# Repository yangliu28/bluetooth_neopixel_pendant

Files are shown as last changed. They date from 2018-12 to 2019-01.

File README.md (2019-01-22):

# bluetooth_neopixel_pendant

The circuit is designed on top of Arduino Micro, but changing the I/O level and clock to 3.3v and 8MHz respectively. The MCU has been loaded the same bootloader and fuses with [Sparkfun Pro Micro](https://www.sparkfun.com/products/12587). To upload program, [install Sparkfun Arduino Boards](https://github.com/sparkfun/Arduino_Boards#installation-instructions) to your Arduino IDE, and choose "Sparkfun Pro Micro" as board, and "Atmega32U4 (3.3v, 8 MHz)" as processor. The onboard bluetooth module HC-06 works only with Android and Windows, not iOS.

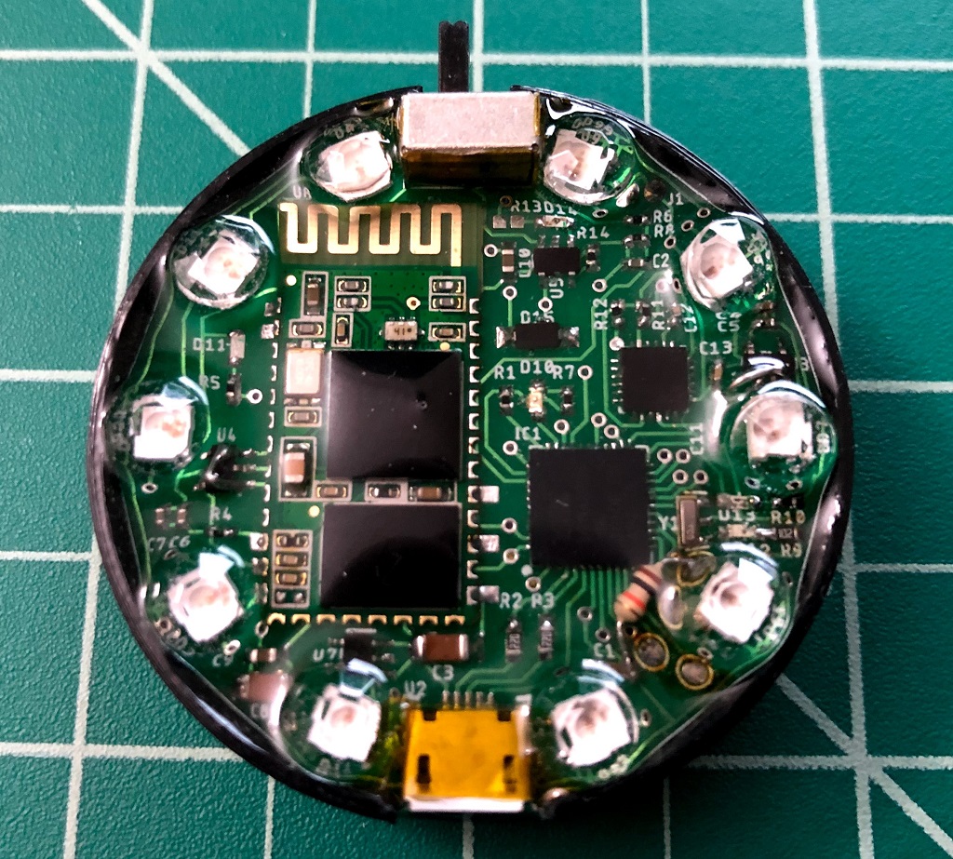
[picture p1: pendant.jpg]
pendant


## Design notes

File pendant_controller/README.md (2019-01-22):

## Hardware design

ATMEGA32U4 has built-in USB interface, for easily reprogramming the device without a USB to serial converter. The system is powered at 3.3v and clocked at 8MHz. Bluetooth module is HC-06 configured in slave mode. RGB LEDs are Neopixel Nano, with a small footprint of 2.4x2.7mm.

Diameter of the circular PCB is 1.7in, radius of 850 mil.

Matlab script to generate pos and orientation of neopixels:
```
d=735;
pos=zeros(10:3);
pos(1:5,1) = 850+d*cos((90+22+34*n)*pi/180);
pos(6:10,1) = 850+d*cos((-90+22+34*n)*pi/180);
pos(1:5,2) = 850+d*sin((90+22+34*n)*pi/180);
pos(6:10,2) = 850+d*sin((-90+22+34*n)*pi/180);
pos(1:5,3) = -180+22+34*n;
pos(6:10,3) = 22+34*n;
```

### Board fix

post-assembly modifications

**Reset pin of ATMEGA32U4 was be pulled up to 3V3 with a 10K resistor**

**Enable pins of two regulators for bluetooth and IMU were not working, because the voltage level of enable pin does not match output. Jumpers were used to keep regulators enabled always.**

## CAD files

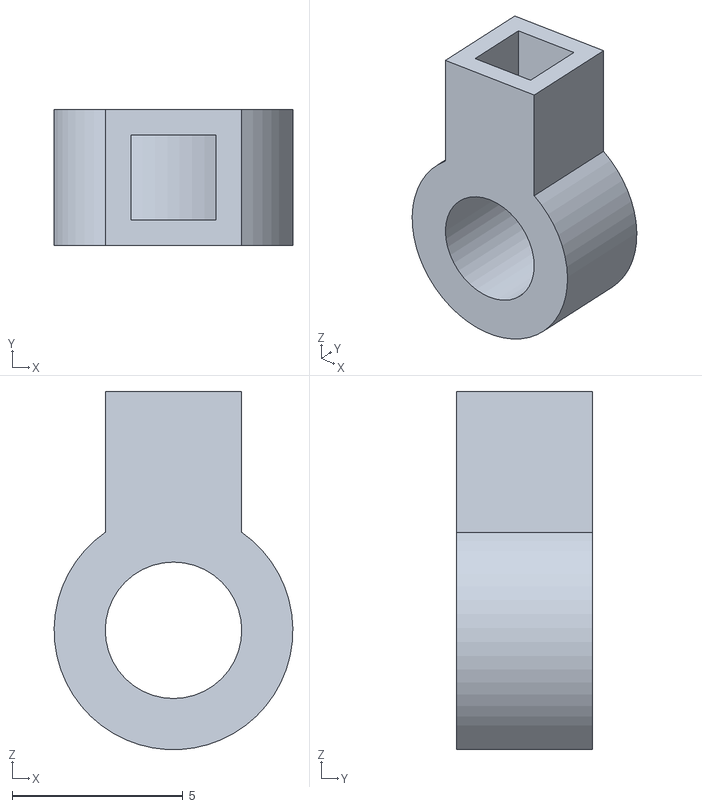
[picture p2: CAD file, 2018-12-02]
pendant case CAD/pendant_connector.STL
7.00 x 4.00 x 10.5

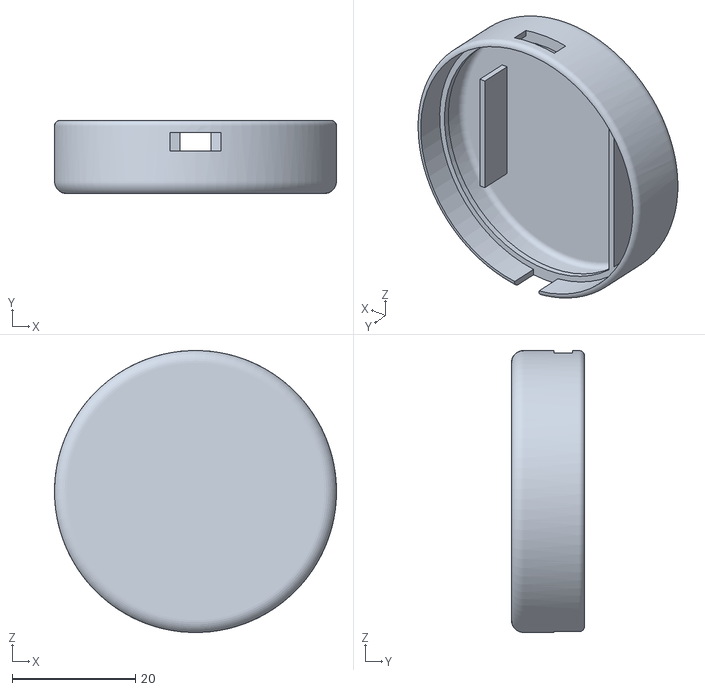
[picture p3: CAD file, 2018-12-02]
pendant case CAD/pendant_case.STL
45.7 x 11.9 x 45.8

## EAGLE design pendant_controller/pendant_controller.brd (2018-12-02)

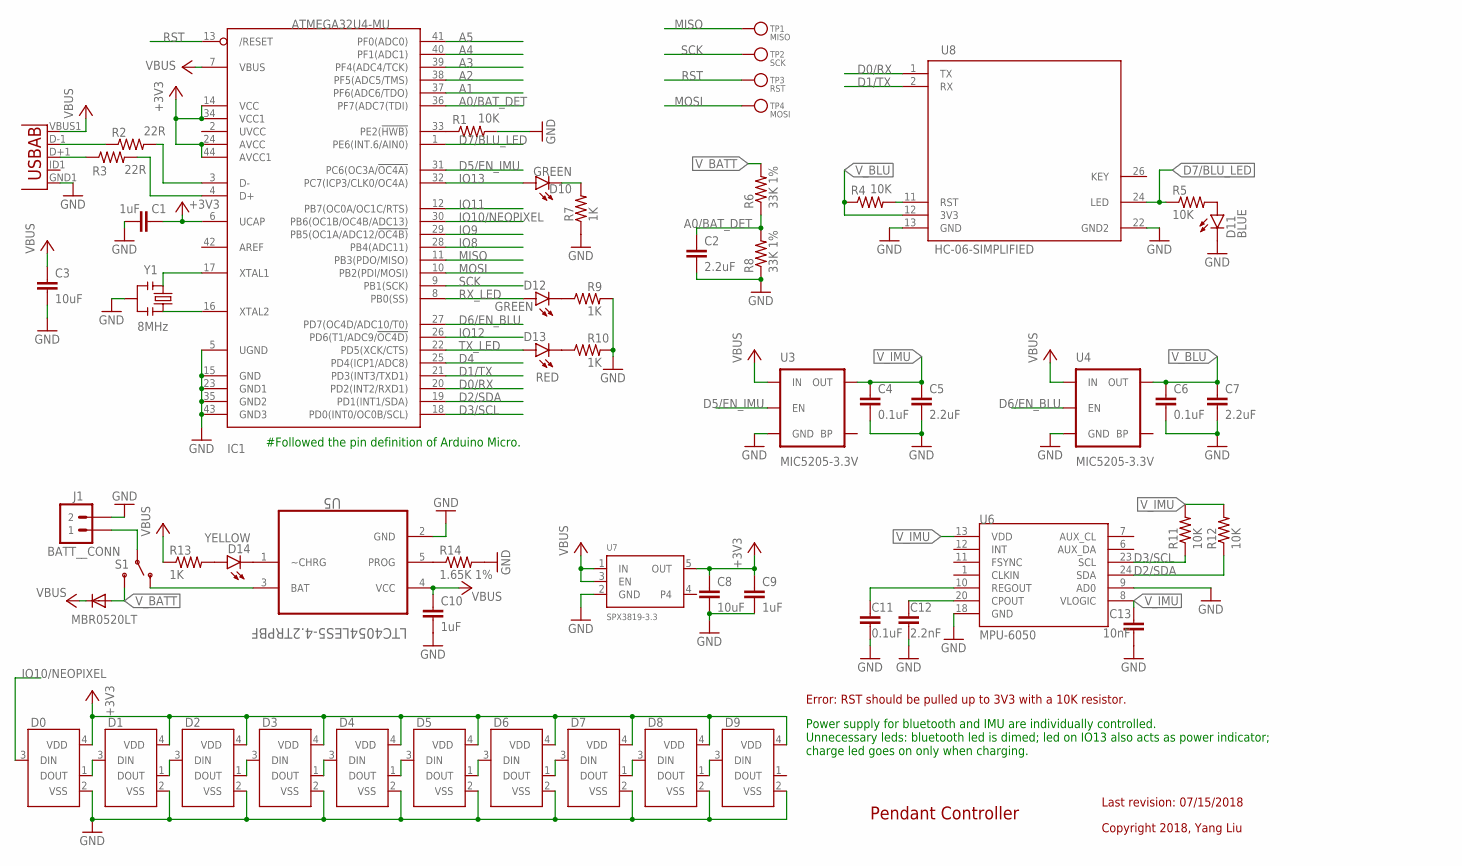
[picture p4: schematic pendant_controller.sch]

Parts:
C1, C9, C10: 1uF; 0603-CAP
C2, C5, C7: 2.2uF; 0402-CAP
C3, C8: 10uF; 1206
C4, C6, C11: 0.1uF; 0402-CAP
C12: 2.2nF; 0402-CAP
C13: 10nF; 0402-CAP
D0, D1, D2, D3, D4, D5, D6, D7, D8, D9: NEOPIXEL-2427; LED2427
D10, D12: GREEN; LED-0603
D11: BLUE; LED-0603
D13: RED; LED-0603
D14: YELLOW; LED-0603
D15: MBR0520LT; SOD123
IC1: ATMEGA32U4-MU; TQFN44_7MM
J1: BATT__CONN; 1X02-SMALL
R1, R4, R5, R11, R12: 10K; 0402-RES
R2, R3: 22R; 0603-RES
R6, R8: 33K 1%; 0402-RES
R7, R9, R10, R13: 1K; 0402-RES
R14: 1.65K 1%; 0402-RES
S1: SWITCH-SPDTPTH; SWITCH-SPDT
TP1: MISO; TESTPOINT_ROUND_1.5MM
TP2: SCK; TESTPOINT_ROUND_1.5MM
TP3: RST; TESTPOINT_ROUND_1.5MM
TP4: MOSI; TESTPOINT_ROUND_1.5MM
U2: USB""; USB-MICRO-SMD
U3, U4: MIC5205-3.3V; SOT23-5
U5: LTC4054LES5-4.2TRPBF; SOT95P280X100-5N
U6: MPU-6050; QFN-24
U7: SPX3819-3.3; SOT23-5
U8: HC-06-SIMPLIFIED; HC-06_SMD
Y1: 8MHz; RESONATOR-SMD

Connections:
+3V3: C1.1, C8.1, C9.1, D0.4 (VDD), D1.4 (VDD), D2.4 (VDD), D3.4 (VDD), D4.4 (VDD), D5.4 (VDD), D6.4 (VDD), D7.4 (VDD), D8.4 (VDD), D9.4 (VDD), IC1.6 (UCAP), IC1.14 (VCC), IC1.24 (AVCC), IC1.34 (VCC1), IC1.44 (AVCC1), U7.5 (OUT)
A0/BAT_DET: C2.1, IC1.36 (PF7(ADC7(TDI)), R6.1, R8.2
A1: IC1.37 (PF6(ADC6/TDO))
A2: IC1.38 (PF5(ADC5/TMS))
A3: IC1.39 (PF4(ADC4/TCK))
A4: IC1.40 (PF1(ADC1))
A5: IC1.41 (PF0(ADC0))
D0/RX: IC1.20 (PD2(INT2/RXD1)), U8.1 (TX)
D1/TX: IC1.21 (PD3(INT3/TXD1)), U8.2 (RX)
D2/SDA: IC1.19 (PD1(INT1/SDA)), R12.1, U6.24 (SDA)
D3/SCL: IC1.18 (PD0(INT0/OC0B/SCL)), R11.1, U6.23 (SCL)
D4: IC1.25 (PD4(ICP1/ADC8))
D5/EN_IMU: IC1.31 (PC6(OC3A/!OC4A)), U3.3 (EN)
D6/EN_BLU: IC1.27 (PD7(OC4D/ADC10/T0)), U4.3 (EN)
D7/BLU_LED: IC1.1 (PE6(INT.6/AIN0)), R5.1, U8.24 (LED)
GND: C1.2, C2.2, C3.2, C4.2, C5.2, C6.2, C7.2, C8.2, C9.2, C10.2, C11.2, C12.2, C13.2, D0.2 (VSS), D1.2 (VSS), D2.2 (VSS), D3.2 (VSS), D4.2 (VSS), D5.2 (VSS), D6.2 (VSS), D7.2 (VSS), D8.2 (VSS), D9.2 (VSS), D11.C, IC1.5 (UGND), IC1.15 (GND), IC1.23 (GND1), IC1.35 (GND2), IC1.43 (GND3), J1.2, R1.2, R7.1, R8.1, R9.2, R10.2, R14.2, U2.GND1 (GND), U3.2 (GND), U4.2 (GND), U5.2 (GND), U6.9 (AD0), U6.18 (GND), U7.2 (GND), U8.13 (GND), U8.22 (GND2), Y1.2
IO8: IC1.28 (PB4(ADC11))
IO9: IC1.29 (PB5(OC1A/ADC12/!OC4B))
IO10/NEOPIXEL: D0.3 (DIN), IC1.30 (PB6(OC1B/OC4B/ADC13))
IO11: IC1.12 (PB7(OC0A/OC1C/RTS))
IO12: IC1.26 (PD6(T1/ADC9/!OC4D))
IO13: D10.A, IC1.32 (PC7(ICP3/CLK0/OC4A))
MISO: IC1.11 (PB3(PDO/MISO)), TP1.P$1
MOSI: IC1.10 (PB2(PDI/MOSI)), TP4.P$1
unnamed: S1.1 (O), U5.3 (BAT)
unnamed: J1.1, S1.2
unnamed: R2.1, U2.D-1 (D-)
unnamed: D14.A, R13.2
unnamed: R3.1, U2.D+1 (D+)
unnamed: IC1.33 (PE2(!HWB)), R1.1
unnamed: IC1.4 (D+), R3.2
unnamed: R14.1, U5.5 (PROG)
unnamed: D14.C, U5.1 (~CHRG)
unnamed: D0.1 (DOUT), D1.3 (DIN)
unnamed: IC1.16 (XTAL2), Y1.3
unnamed: IC1.17 (XTAL1), Y1.1
unnamed: IC1.3 (D-), R2.2
unnamed: D12.C, R9.1
unnamed: D13.C, R10.1
unnamed: C12.1, U6.20 (CPOUT)
unnamed: C11.1, U6.10 (REGOUT)
unnamed: R4.2, U8.11 (RST)
unnamed: D10.C, R7.2
unnamed: D11.A, R5.2
unnamed: D1.1 (DOUT), D2.3 (DIN)
unnamed: D2.1 (DOUT), D3.3 (DIN)
unnamed: D3.1 (DOUT), D4.3 (DIN)
unnamed: D4.1 (DOUT), D5.3 (DIN)
unnamed: D5.1 (DOUT), D6.3 (DIN)
unnamed: D6.1 (DOUT), D7.3 (DIN)
unnamed: D7.1 (DOUT), D8.3 (DIN)
unnamed: D8.1 (DOUT), D9.3 (DIN)
RST: IC1.13 (/RESET), TP3.P$1
RX_LED: D12.A, IC1.8 (PB0(SS))
SCK: IC1.9 (PB1(SCK)), TP2.P$1
TX_LED: D13.A, IC1.22 (PD5(XCK/CTS))
VBUS: C3.1, C10.1, D15.C, IC1.7 (VBUS), R13.1, U2.VBUS1 (VBUS), U3.1 (IN), U4.1 (IN), U5.4 (VCC), U7.1 (IN), U7.3 (EN)
V_BATT: D15.A, R6.2, S1.3 (S)
V_BLU: C6.1, C7.1, R4.1, U4.5 (OUT), U8.12 (3V3)
V_IMU: C4.1, C5.1, C13.1, R11.2, R12.2, U3.5 (OUT), U6.8 (VLOGIC), U6.13 (VDD)

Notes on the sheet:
Last revision: 07/15/2018
Copyright 2018, Yang Liu
Pendant Controller
#Followed the pin definition of Arduino Micro.
Power supply for bluetooth and IMU are individually controlled. Unnecessary leds: bluetooth led is dimed; led on IO13 also acts as power indicator; charge led goes on only when charging.
Error: RST should be pulled up to 3V3 with a 10K resistor.

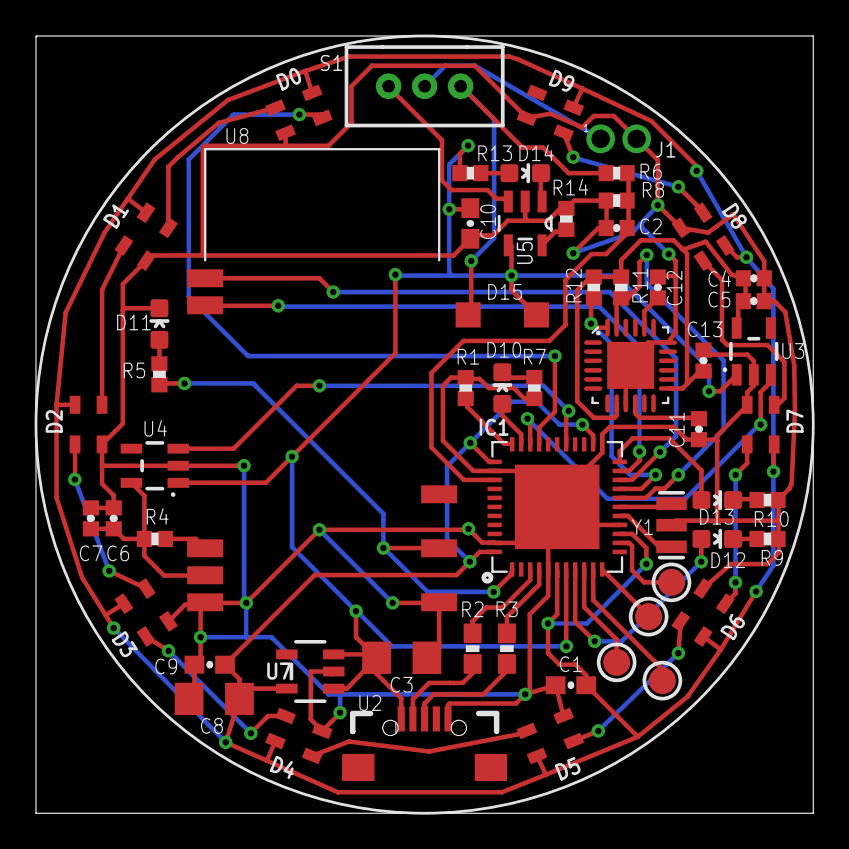
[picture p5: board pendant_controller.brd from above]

Board: 2 copper layers, 43.2 x 43.2 mm, 58 parts (0 on the bottom side), 50 nets.

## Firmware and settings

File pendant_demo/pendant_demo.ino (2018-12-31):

// This is the demo program for this bluetooth-neopixel pendant.
// Author: Yang Liu, 12/04/2018.

// Received string should end with carriage return(13), then line feed(10)
// Bluetooth command format: keyword + space + argument(optional)
// Singular commands
    // "rainbow", rainbow mode
// Combinational commands:
    // "brightness ##", 1 min brightness, 0 max brightness, 255 just below max
    // "all color_name", set all neopixels to same color
    // "led# color_name", addressing neopixels individuallly, number from 0 to 9
    // "gravity color_name", gravity mode
// Supported color names:
// white, black, maroon, brown, olive, teal, navy, red, orange, yellow, lime
// green, cyan, blue, pruple, magenta, grey, pink, apricot, beige, mint, lavender

// The circuit board shares the same body frame with the IMU.
// If facing the PCB, x axis points to the right,
// y axis points up to the switch, z axis points out from the board.

// List of distinct colors:
// https://sashat.me/2017/01/11/list-of-20-simple-distinct-colors/

#include <Adafruit_NeoPixel.h>
#include "Wire.h"
#include "I2Cdev.h"
#include "MPU6050.h"
#include "math.h"

#define NEOPIXEL_PIN 10
#define NEOPIXEL_NUM 10
#define MPU6050_ADDRESS 0x68
#define BUFFER_LEN 20
#define BATTERY_MEASURE A0
#define LED13 13

// MPU6050 variables
MPU6050 mpu6050;
int16_t accelCount[3];  // Stores the 16-bit signed accelerometer sensor output
float ax, ay, az;       // Stores the real accel value in g's
int16_t gyroCount[3];   // Stores the 16-bit signed gyro sensor output
float gx, gy, gz;       // Stores the real gyro value in degrees per seconds
float aRes = 2.0/32768.0;
float gRes = 250.0/32768.0;
float q[4] = {1.0f, 0.0f, 0.0f, 0.0f};  // vector to hold quaternion
float roll, pitch, yaw;  // in degrees
// for quaternion update
float GyroMeasError = PI * (40.0f / 180.0f);     // gyroscope measurement error in rads/s (start at 60 deg/s), then reduce after ~10 s to 3
float beta = sqrt(3.0f / 4.0f) * GyroMeasError;  // compute beta
float GyroMeasDrift = PI * (2.0f / 180.0f);      // gyroscope measurement drift in rad/s/s (start at 0.0 deg/s/s)
float zeta = sqrt(3.0f / 4.0f) * GyroMeasDrift;  // compute zeta, the other free parameter in the Madgwick scheme usually set to a small or zero value
float deltat = 0.0f;
float p_vect[3];

// Neopixel variables
Adafruit_NeoPixel pixels = Adafruit_NeoPixel(NEOPIXEL_NUM, NEOPIXEL_PIN, NEO_GRB + NEO_KHZ800);
uint32_t color_white = pixels.Color(255,255,255);
uint32_t color_black = pixels.Color(0,0,0);
uint32_t color_maroon = pixels.Color(128,0,0);
uint32_t color_brown = pixels.Color(170,110,40);
uint32_t color_olive = pixels.Color(128,128,0);
uint32_t color_teal = pixels.Color(0,128,128);
uint32_t color_navy = pixels.Color(0,0,128);
uint32_t color_red = pixels.Color(230,25,75);
uint32_t color_orange = pixels.Color(245,130,48);
uint32_t color_yellow = pixels.Color(255,255,25);
uint32_t color_lime = pixels.Color(210,245,60);
uint32_t color_green = pixels.Color(60,180,75);
uint32_t color_cyan = pixels.Color(70,240,240);
uint32_t color_blue = pixels.Color(0,130,200);
uint32_t color_purple = pixels.Color(145,30,180);
uint32_t color_magenta = pixels.Color(240,50,230);
uint32_t color_grey = pixels.Color(128,128,128);
uint32_t color_pink = pixels.Color(250,190,190);
uint32_t color_apricot = pixels.Color(255,215,180);
uint32_t color_beige = pixels.Color(255,250,200);
uint32_t color_mint = pixels.Color(170,255,195);
uint32_t color_lavender = pixels.Color(170,190,255);
int rainbow_index = 0;
uint32_t gravity_color;
uint8_t gravity_pixel_last = 0;

// bluetooth control variables
char buffer[BUFFER_LEN];
uint8_t buffer_index;
enum MODE {ADDRESSING_MODE, RAINBOW_MODE, GRAVITY_MODE};
MODE mode;

// flow control
unsigned long time_last, time_now;  // microsecond
unsigned long period = 20000;  // period for main loop
// debug print control
unsigned long debug_period = 100000;
uint8_t debug_freq = (uint8_t)((float)debug_period/period);
uint8_t debug_count = 0;

void setup() {
    Serial.begin(9600);  // USB
    Serial1.begin(9600);  // bluetooth
    Serial.setTimeout(100);

    // mpu6050
    Wire.begin();  // join I2C bus
    calibrateGyro();
    mpu6050.initialize();

    // neopixels
    mode = ADDRESSING_MODE;
    pixels.begin();
    set_all(color_black);
    pixels.setBrightness(50);
    pixels.show();

    digitalWrite(LED13, HIGH);
    Serial.print("battery voltage: ");
    Serial.print(analogRead(BATTERY_MEASURE)*3.3/1023.0*2.0);

    time_last = micros();
}

void loop() {
    time_now = micros();
    if ((time_now - time_last) > period) {
        deltat = (time_now - time_last)/1000000.0f;
        time_last = time_now;

        // read raw accel/gyro measurements from device
        mpu6050.getMotion6(&accelCount[0], &accelCount[1], &accelCount[2],
            &gyroCount[0], &gyroCount[1], &gyroCount[2]);
        ax = (float)accelCount[0] * aRes;  // get actual g value
        ay = (float)accelCount[1] * aRes;
        az = (float)accelCount[2] * aRes;
        gx = (float)gyroCount[0] * gRes;  // get actual gyro value
        gy = (float)gyroCount[1] * gRes;
        gz = (float)gyroCount[2] * gRes;

        // quaternion update
        MadgwickQuaternionUpdate(ax, ay, az, gx*PI/180.f, gy*PI/180.f, gz*PI/180.f);
        // roll = atan2(2.0f * (q[0] * q[1] + q[2] * q[3]), q[0] * q[0] - q[1] * q[1] - q[2] * q[2] + q[3] * q[3]);
        // pitch = -asin(2.0f * (q[1] * q[3] - q[0] * q[2]));
        // yaw = atan2(2.0f * (q[1] * q[2] + q[0] * q[3]), q[0] * q[0] + q[1] * q[1] - q[2] * q[2] - q[3] * q[3]);
        // roll *= 180.0f / PI;
        // pitch *= 180.0f / PI;
        // yaw *= 180.0f / PI;

        // projection of pointing-up unit vector in inertial frame to IMU's body frame
        p_vect[0] = 2*(q[1]*q[3] - q[0]*q[2]);
        p_vect[1] = 2*(q[0]*q[1] + q[2]*q[3]);
        p_vect[2] = q[0]*q[0] - q[1]*q[1] - q[2]*q[2] + q[3]*q[3];

        // debug print
        debug_count = debug_count + 1;
        if (debug_count > debug_freq) {
            debug_count = 0;
            // Serial.print(ax); Serial.print("\t");
            // Serial.print(ay); Serial.print("\t");
            // Serial.print(az); Serial.print("\t");
            // Serial.print(gx); Serial.print("\t");
            // Serial.print(gy); Serial.print("\t");
            // Serial.print(gz);
            // Serial.print(roll); Serial.print("\t");
            // Serial.print(pitch); Serial.print("\t");
            // Serial.print(yaw);
            // Serial.print(p_vect[0]); Serial.print("\t");
            // Serial.print(p_vect[1]); Serial.print("\t");
            // Serial.print(p_vect[2]);
            // Serial.println("");
        }

        // read bluetooth command
        for (uint8_t i=0; i<BUFFER_LEN; i++) {
            buffer[i] = 0;
        }
        if (Serial1.available()) {
            int command_len;
            // read until the line feed character
            command_len = Serial1.readBytesUntil(10, buffer, BUFFER_LEN);
            Serial.println(buffer);
            if (buffer[command_len-1] == 13) {
                // look for the first space
                uint8_t space_found = 0;
                uint8_t space_pos = 0;
                for (uint8_t i=0; i<command_len-1; i++) {
                    if (buffer[i] == ' ') {
                        space_found = 1;
                        space_pos = i;
                        break;
                    }
                }
                if (!space_found) {
                    // match singular commands
                    if (match_str(buffer, command_len-1, "rainbow")) {
                        mode = RAINBOW_MODE;
                        set_all(color_black);
                    }
                }
                else if (space_found && space_pos != 0 && space_pos != command_len-2) {
                    // match combinational commands, if space is not the first/last character
                    if (match_str(buffer, space_pos, "brightness")) {
                        int input_brightness = atoi(buffer+space_pos);
                        Serial.print("received brightness: ");
                        Serial.println(input_brightness);
                        if (input_brightness >= 0 && input_brightness <= 255) {
                            pixels.setBrightness(uint8_t(input_brightness));
                        }
                    }
                    else if (match_str(buffer, space_pos, "all")) {
                        uint32_t input_color;
                        if (match_color(buffer+space_pos+1, command_len-space_pos-2, &input_color)) {
                            mode = ADDRESSING_MODE;
                            set_all(input_color);
                        }
                    }
                    else if (match_str(buffer, space_pos-1, "led")) {
                        uint8_t input_index = buffer[space_pos-1] - 48;
                        uint32_t input_color;
                        if (match_color(buffer+space_pos+1, command_len-space_pos-2, &input_color)) {
                            if (mode != ADDRESSING_MODE) {
                                mode = ADDRESSING_MODE;
                                set_all(color_black);
                            }
                            pixels.setPixelColor(input_index, input_color);
                        }
                    }
                    else if (match_str(buffer, space_pos, "gravity")) {
                        if (match_color(buffer+space_pos+1, command_len-space_pos-2, &gravity_color)) {
                            mode = GRAVITY_MODE;
                            set_all(color_black);
                        }
                    }
                }
            }
        }

        // update pixel color variables
        if (mode == RAINBOW_MODE) {
            for (uint8_t i=0; i<NEOPIXEL_NUM; i++) {
                pixels.setPixelColor(i, pixel_wheel((i * 256 / 25 + rainbow_index) & 255));
            }
            rainbow_index = rainbow_index + 2;
        }
        else if (mode == GRAVITY_MODE) {
            pixels.setPixelColor(gravity_pixel_last, color_black);
            uint8_t gravity_pixel = (uint8_t(reset_range(atan2(p_vect[1], p_vect[0])+2*PI/20) / (2*PI/10)) + 7 - 5) % 10;
            pixels.setPixelColor(gravity_pixel, gravity_color);
            gravity_pixel_last = gravity_pixel;
        }

        pixels.show();
    }
}

double reset_range(double rad) {
    while (rad < 0) {
        rad += 2*PI;
    }
    return rad;
}

// map input string to a color
uint8_t match_color(char* input, uint8_t input_len, uint32_t* return_color) {
    if (match_str(input, input_len, "white")) {
        *return_color = color_white;
        return 1;
    }
    else if (match_str(input, input_len, "black")) {
        *return_color = color_black;
        return 1;
    }
    else if (match_str(input, input_len, "maroon")) {
        *return_color = color_maroon;
        return 1;
    }
    else if (match_str(input, input_len, "brown")) {
        *return_color = color_brown;
        return 1;
    }
    else if (match_str(input, input_len, "olive")) {
        *return_color = color_olive;
        return 1;
    }
    else if (match_str(input, input_len, "teal")) {
        *return_color = color_teal;
        return 1;
    }
    else if (match_str(input, input_len, "navy")) {
        *return_color = color_navy;
        return 1;
    }
    else if (match_str(input, input_len, "red")) {
        *return_color = color_red;
        return 1;
    }
    else if (match_str(input, input_len, "orange")) {
        *return_color = color_orange;
        return 1;
    }
    else if (match_str(input, input_len, "yellow")) {
        *return_color = color_yellow;
        return 1;
    }
    else if (match_str(input, input_len, "lime")) {
        *return_color = color_lime;
        return 1;
    }
    else if (match_str(input, input_len, "green")) {
        *return_color = color_green;
        return 1;
    }
    else if (match_str(input, input_len, "cyan")) {
        *return_color = color_cyan;
        return 1;
    }
    else if (match_str(input, input_len, "blue")) {
        *return_color = color_blue;
        return 1;
    }
    else if (match_str(input, input_len, "purple")) {
        *return_color = color_purple;
        return 1;
    }
    else if (match_str(input, input_len, "magenta")) {
        *return_color = color_magenta;
        return 1;
    }
    else if (match_str(input, input_len, "grey")) {
        *return_color = color_grey;
        return 1;
    }
    else if (match_str(input, input_len, "pink")) {
        *return_color = color_pink;
        return 1;
    }
    else if (match_str(input, input_len, "apricot")) {
        *return_color = color_apricot;
        return 1;
    }
    else if (match_str(input, input_len, "beige")) {
        *return_color = color_beige;
        return 1;
    }
    else if (match_str(input, input_len, "mint")) {
        *return_color = color_mint;
        return 1;
    }
    else if (match_str(input, input_len, "lavender")) {
        *return_color = color_lavender;
        return 1;
    }
    return 0;
}

// check if input string match the command
uint8_t match_str(char* input, uint8_t input_len, char* cmd) {
    if (input_len != strlen(cmd)) {
        return 0;
    }
    for (uint8_t i=0; i<input_len; i++) {
        if (*(input+i) != *(cmd+i)) {
            return 0;
        }
    }
    return 1;
}

// set all neopixels to one color
void set_all(uint32_t color) {
    for (uint8_t i=0; i<NEOPIXEL_NUM; i++) {
        pixels.setPixelColor(i, color);
    }
}

// Input a value 0 to 255 to get a color value.
// The colours are a transition r - g - b - back to r.
uint32_t pixel_wheel(byte WheelPos) {
    WheelPos = 255 - WheelPos;
    if(WheelPos < 85)
    {
        return pixels.Color(255 - WheelPos * 3, 0, WheelPos * 3);
    }
    else if(WheelPos < 170)
    {
        WheelPos -= 85;
        return pixels.Color(0, WheelPos * 3, 255 - WheelPos * 3);
    }
    else
    {
        WheelPos -= 170;
        return pixels.Color(WheelPos * 3, 255 - WheelPos * 3, 0);
    }
}

// Implementation of Sebastian Madgwick's "...efficient orientation filter for... inertial/magnetic sensor arrays"
// (see http://www.x-io.co.uk/category/open-source/ for examples and more details)
// which fuses acceleration and rotation rate to produce a quaternion-based estimate of relative
// device orientation -- which can be converted to yaw, pitch, and roll. Useful for stabilizing quadcopters, etc.
// The performance of the orientation filter is at least as good as conventional Kalman-based filtering algorithms
// but is much less computationally intensive---it can be performed on a 3.3 V Pro Mini operating at 8 MHz!
void MadgwickQuaternionUpdate(float ax, float ay, float az, float gx, float gy, float gz)
{
    float q1 = q[0], q2 = q[1], q3 = q[2], q4 = q[3];         // short name local variable for readability
    float norm;                                               // vector norm
    float f1, f2, f3;                                         // objetive funcyion elements
    float J_11or24, J_12or23, J_13or22, J_14or21, J_32, J_33; // objective function Jacobian elements
    float qDot1, qDot2, qDot3, qDot4;
    float hatDot1, hatDot2, hatDot3, hatDot4;
    float gerrx, gerry, gerrz, gbiasx, gbiasy, gbiasz;        // gyro bias error

    // Auxiliary variables to avoid repeated arithmetic
    float _halfq1 = 0.5f * q1;
    float _halfq2 = 0.5f * q2;
    float _halfq3 = 0.5f * q3;
    float _halfq4 = 0.5f * q4;
    float _2q1 = 2.0f * q1;
    float _2q2 = 2.0f * q2;
    float _2q3 = 2.0f * q3;
    float _2q4 = 2.0f * q4;
    float _2q1q3 = 2.0f * q1 * q3;
    float _2q3q4 = 2.0f * q3 * q4;

    // Normalise accelerometer measurement
    norm = sqrt(ax * ax + ay * ay + az * az);
    if (norm == 0.0f) return; // handle NaN
    norm = 1.0f/norm;
    ax *= norm;
    ay *= norm;
    az *= norm;

    // Compute the objective function and Jacobian
    f1 = _2q2 * q4 - _2q1 * q3 - ax;
    f2 = _2q1 * q2 + _2q3 * q4 - ay;
    f3 = 1.0f - _2q2 * q2 - _2q3 * q3 - az;
    J_11or24 = _2q3;
    J_12or23 = _2q4;
    J_13or22 = _2q1;
    J_14or21 = _2q2;
    J_32 = 2.0f * J_14or21;
    J_33 = 2.0f * J_11or24;

    // Compute the gradient (matrix multiplication)
    hatDot1 = J_14or21 * f2 - J_11or24 * f1;
    hatDot2 = J_12or23 * f1 + J_13or22 * f2 - J_32 * f3;
    hatDot3 = J_12or23 * f2 - J_33 *f3 - J_13or22 * f1;
    hatDot4 = J_14or21 * f1 + J_11or24 * f2;

    // Normalize the gradient
    norm = sqrt(hatDot1 * hatDot1 + hatDot2 * hatDot2 + hatDot3 * hatDot3 + hatDot4 * hatDot4);
    hatDot1 /= norm;
    hatDot2 /= norm;
    hatDot3 /= norm;
    hatDot4 /= norm;

    // Compute estimated gyroscope biases
    gerrx = _2q1 * hatDot2 - _2q2 * hatDot1 - _2q3 * hatDot4 + _2q4 * hatDot3;
    gerry = _2q1 * hatDot3 + _2q2 * hatDot4 - _2q3 * hatDot1 - _2q4 * hatDot2;
    gerrz = _2q1 * hatDot4 - _2q2 * hatDot3 + _2q3 * hatDot2 - _2q4 * hatDot1;

    // Compute and remove gyroscope biases
    gbiasx += gerrx * deltat * zeta;
    gbiasy += gerry * deltat * zeta;
    gbiasz += gerrz * deltat * zeta;
    gx -= gbiasx;
    gy -= gbiasy;
    gz -= gbiasz;

    // Compute the quaternion derivative
    qDot1 = -_halfq2 * gx - _halfq3 * gy - _halfq4 * gz;
    qDot2 =  _halfq1 * gx + _halfq3 * gz - _halfq4 * gy;
    qDot3 =  _halfq1 * gy - _halfq2 * gz + _halfq4 * gx;
    qDot4 =  _halfq1 * gz + _halfq2 * gy - _halfq3 * gx;

    // Compute then integrate estimated quaternion derivative
    q1 += (qDot1 -(beta * hatDot1)) * deltat;
    q2 += (qDot2 -(beta * hatDot2)) * deltat;
    q3 += (qDot3 -(beta * hatDot3)) * deltat;
    q4 += (qDot4 -(beta * hatDot4)) * deltat;

    // Normalize the quaternion
    norm = sqrt(q1 * q1 + q2 * q2 + q3 * q3 + q4 * q4);    // normalise quaternion
    norm = 1.0f/norm;
    q[0] = q1 * norm;
    q[1] = q2 * norm;
    q[2] = q3 * norm;
    q[3] = q4 * norm;
}

void writeByte(uint8_t address, uint8_t subAddress, uint8_t data)
{
    Wire.beginTransmission(address);  // Initialize the Tx buffer
    Wire.write(subAddress);           // Put slave register address in Tx buffer
    Wire.write(data);                 // Put data in Tx buffer
    Wire.endTransmission();           // Send the Tx buffer
}

uint8_t readByte(uint8_t address, uint8_t subAddress)
{
    uint8_t data; // `data` will store the register data     
    Wire.beginTransmission(address);         // Initialize the Tx buffer
    Wire.write(subAddress);                  // Put slave register address in Tx buffer
    Wire.endTransmission(false);             // Send the Tx buffer, but send a restart to keep connection alive
    Wire.requestFrom(address, (uint8_t) 1);  // Read one byte from slave register address 
    data = Wire.read();                      // Fill Rx buffer with result
    return data;                             // Return data read from slave register
}

void readBytes(uint8_t address, uint8_t subAddress, uint8_t count, uint8_t * dest)
{  
    Wire.beginTransmission(address);   // Initialize the Tx buffer
    Wire.write(subAddress);            // Put slave register address in Tx buffer
    Wire.endTransmission(false);       // Send the Tx buffer, but send a restart to keep connection alive
    uint8_t i = 0;
    Wire.requestFrom(address, count);  // Read bytes from slave register address 
    while (Wire.available()) {
        dest[i++] = Wire.read(); }         // Put read results in the Rx buffer
}
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

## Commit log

2018-12-02 initial commit
    board design and case CAD
    [pendant_case.STL, pendant_connector.STL, pendant_controller.brd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]
2018-12-03 fix regulator not enabled problem
    [pendant_controller.sch]
2018-12-03 update bt not working on ios
    [pendant_demo.ino]
2018-12-03 update board fix image
2018-12-04 debug print
2018-12-31 battery voltage measurement

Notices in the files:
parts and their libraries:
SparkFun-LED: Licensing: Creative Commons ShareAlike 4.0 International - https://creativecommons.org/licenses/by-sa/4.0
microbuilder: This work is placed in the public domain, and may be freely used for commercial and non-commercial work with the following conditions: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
